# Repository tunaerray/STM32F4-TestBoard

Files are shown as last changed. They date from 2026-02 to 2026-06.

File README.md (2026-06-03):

# STM32F405RGT6 Test Board Hardware Design

A custom-designed embedded development and test board based on the **STM32F405RGT6** microcontroller.
This project focuses on creating a reliable, protected, and programmable STM32-based hardware platform with multiple communication interfaces and a robust power architecture.

## Overview

The board was designed as a programmable STM32F405RGT6-based embedded development platform. It includes common communication interfaces such as **UART**, **I2C**, and **USB**, along with power input protection and programming support.

The hardware design also includes protection mechanisms for safer operation, such as reverse polarity protection, overcurrent protection, and USB ESD protection.

## Features

* STM32F405RGT6 microcontroller
* UART communication interface
* I2C communication interface
* USB interface
* SWD programming support
* External 16 MHz clock circuit
* 12V external power input support
* USB 5V power input support
* Reverse polarity protection
* Overcurrent protection
* USB ESD protection
* Buck converter-based power stage
* 4-layer PCB design
* Signal integrity and power integrity considerations

## Hardware Design

The board includes two different power input paths:

* **12V external input**
* **USB 5V input**

Both input paths were designed with protection in mind. The external power input includes reverse polarity and overcurrent protection, while the USB line includes ESD protection to improve reliability during development and testing.

A buck converter-based power stage is used to generate a safe and stable voltage level for the STM32 microcontroller and peripheral circuits.

## PCB Design

The PCB was designed as a **4-layer board** to improve routing quality, power distribution, and signal integrity.
The layout was created by considering:

* Power integrity
* Signal integrity
* Proper decoupling
* Short and clean clock routing
* Stable MCU power delivery
* USB and communication line protection

## Images

### PCB Front

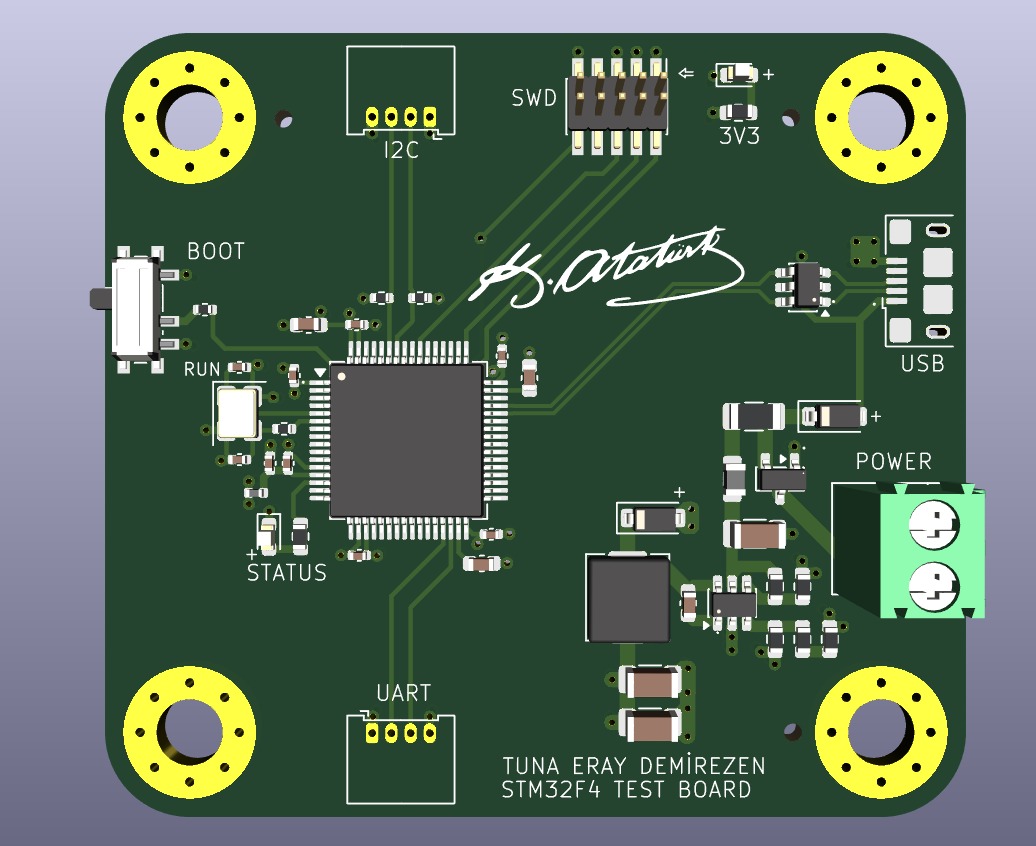
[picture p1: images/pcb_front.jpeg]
PCB Front


### PCB Back

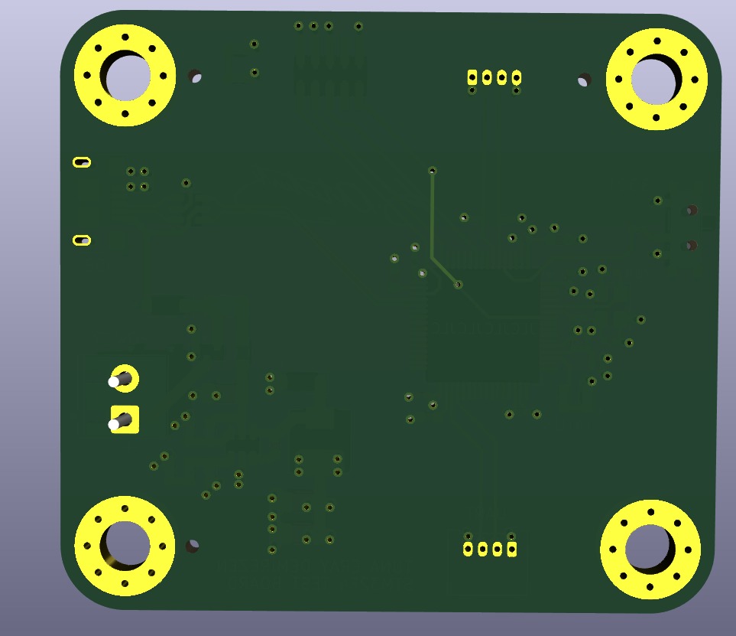
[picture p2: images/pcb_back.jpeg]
PCB Back


## Project Purpose

The main purpose of this project is to create a reliable STM32F405RGT6-based test and development board that can be used for embedded software development, peripheral testing, and hardware validation.

## Technologies Used

* STM32F405RGT6
* KiCad
* 4-layer PCB design
* Buck converter power stage
* UART
* I2C
* USB
* SWD programming interface

## Status

Hardware design completed and PCB files prepared for production.

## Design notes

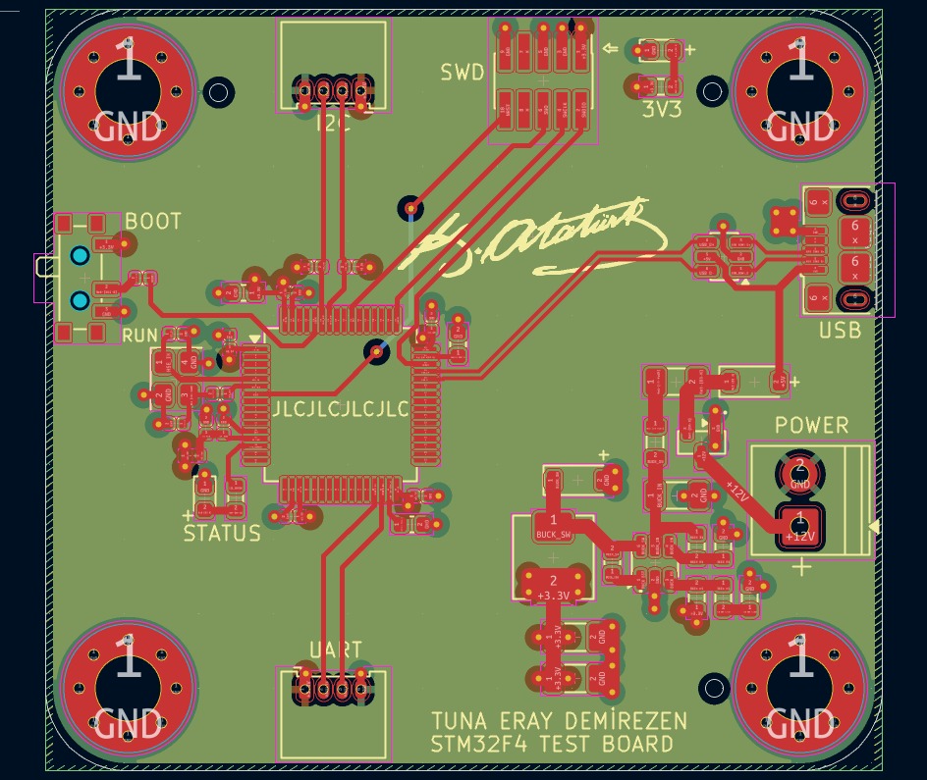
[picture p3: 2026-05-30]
images/pcb_layout.jpeg

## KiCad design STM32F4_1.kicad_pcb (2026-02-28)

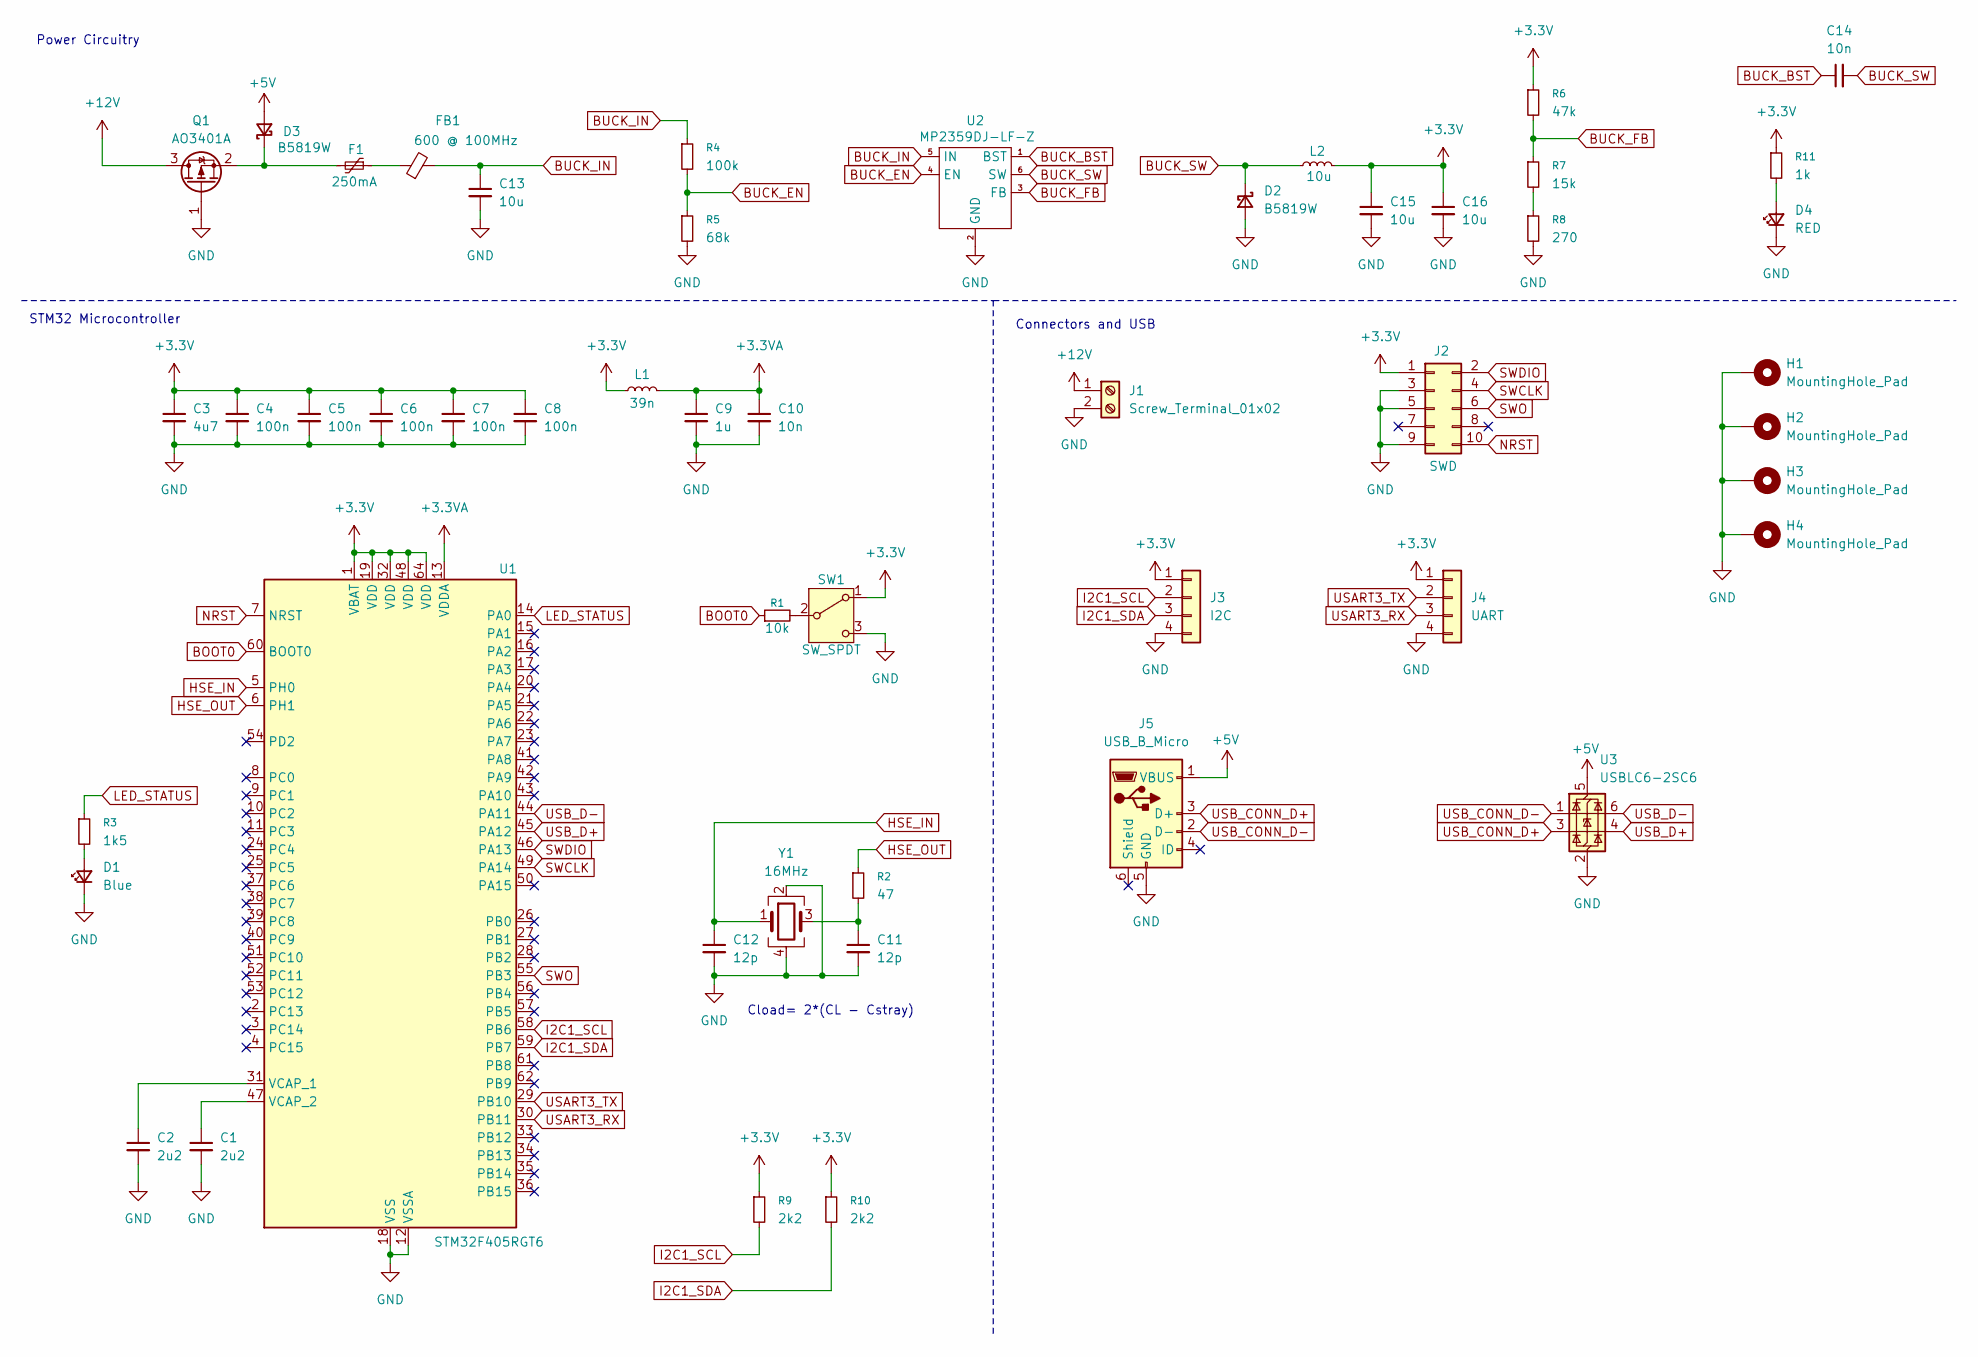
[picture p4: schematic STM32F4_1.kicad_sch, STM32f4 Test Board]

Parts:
C1, C2: 2u2; C_0603_1608Metric
C3: 4u7; C_0603_1608Metric
C4, C5, C6, C7, C8: 100n; C_0402_1005Metric
C9: 1u; C_0402_1005Metric
C10: 10n; C_0402_1005Metric
C11, C12: 12p; C_0402_1005Metric
C13, C15, C16: 10u; C_1206_3216Metric
C14: 10n; C_0603_1608Metric
D1: Blue; LED_0603_1608Metric
D2, D3: B5819W; D_SOD-123
D4: RED; LED_0603_1608Metric
F1: 250mA; Fuse_1206_3216Metric
FB1: 600 @ 100MHz; L_0805_2012Metric
H1, H2, H3, H4: MountingHole_Pad; MountingHole_4.3mm_M4_Pad_Via
J1: Screw_Terminal_01x02; TerminalBlock_Phoenix_PT-1,5-2-3.5-H_1x02_P3.50mm_Horizontal
J2: SWD; PinHeader_2x05_P1.27mm_Vertical_SMD
J3: I2C; Molex_PicoBlade_53048-0410_1x04_P1.25mm_Horizontal
J4: UART; Molex_PicoBlade_53048-0410_1x04_P1.25mm_Horizontal
J5: USB_B_Micro; USB_Micro-B_Amphenol_10118193-0002LF_Horizontal
L1: 39n; L_0402_1005Metric
L2: 10u; L_Sunlord_MWSA0518S
Q1: AO3401A; SOT-23
R1: 10k; R_0402_1005Metric
R2: 47; R_0402_1005Metric
R3: 1k5; R_0603_1608Metric
R4: 100k; R_0603_1608Metric
R5: 68k; R_0603_1608Metric
R6: 47k; R_0603_1608Metric
R7: 15k; R_0603_1608Metric
R8: 270; R_0603_1608Metric
R9, R10: 2k2; R_0402_1005Metric
R11: 1k; R_0603_1608Metric
SW1: SW_SPDT; SW_SPDT_PCM12
U1: STM32F405RGT6; LQFP-64_10x10mm_P0.5mm
U2: MP2359DJ-LF-Z; TSOT-23-6
U3: USBLC6-2SC6; SOT-23-6
Y1: 16MHz; Crystal_SMD_3225-4Pin_3.2x2.5mm

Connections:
+3.3V: C3.1, C4.1, C5.1, C6.1, C7.1, C8.1, C15.1, C16.1, J2.1, J3.1, J4.1, L1.1, L2.2, R6.1, R9.1, R10.1, R11.1, SW1.1 (A), U1.1 (VBAT), U1.19 (VDD), U1.32 (VDD), U1.48 (VDD), U1.64 (VDD)
+3.3VA: C9.1, C10.1, L1.2, U1.13 (VDDA)
+5V: D3.2 (A), J5.1 (VBUS), U3.5 (VBUS)
+12V: J1.1, Q1.3 (D)
BOOT0: R1.1, U1.60 (BOOT0)
BUCK_BST: C14.1, U2.1 (BST)
BUCK_EN: R4.2, R5.1, U2.4 (EN)
BUCK_FB: R6.2, R7.1, U2.3 (FB)
BUCK_IN: C13.1, FB1.2, R4.1, U2.5 (IN)
BUCK_SW: C14.2, D2.1 (K), L2.1, U2.6 (SW)
GND: C1.2, C2.2, C3.2, C4.2, C5.2, C6.2, C7.2, C8.2, C9.2, C10.2, C11.2, C12.2, C13.2, C15.2, C16.2, D1.1 (K), D2.2 (A), D4.1 (K), H1.1, H2.1, H3.1, H4.1, J1.2, J2.3, J2.5, J2.9, J3.4, J4.4, J5.5 (GND), Q1.1 (G), R5.2, R8.2, SW1.3 (C), U1.12 (VSSA), U1.18 (VSS), U1.63 (VSS), U2.2 (GND), U3.2 (GND), Y1.2, Y1.4
HSE_IN: C12.1, U1.5 (PH0), Y1.1
HSE_OUT: R2.1, U1.6 (PH1)
I2C1_SCL: J3.2, R9.2, U1.58 (PB6)
I2C1_SDA: J3.3, R10.2, U1.59 (PB7)
LED_STATUS: R3.1, U1.14 (PA0)
NRST: J2.10, U1.7 (NRST)
unnamed: C11.1, R2.2, Y1.3
unnamed: D1.2 (A), R3.2
unnamed: D3.1 (K), F1.2, Q1.2 (S)
unnamed: D4.2 (A), R11.2
unnamed: F1.1, FB1.1
unnamed: R7.2, R8.1
unnamed: R1.2, SW1.2 (B)
unnamed: C2.1, U1.31 (VCAP_1)
unnamed: C1.1, U1.47 (VCAP_2)
SWCLK: J2.4, U1.49 (PA14)
SWDIO: J2.2, U1.46 (PA13)
SWO: J2.6, U1.55 (PB3)
USART3_RX: J4.3, U1.30 (PB11)
USART3_TX: J4.2, U1.29 (PB10)
USB_CONN_D+: J5.3 (D+), U3.3 (I/O2)
USB_CONN_D-: J5.2 (D-), U3.1 (I/O1)
USB_D+: U1.45 (PA12), U3.4 (I/O2)
USB_D-: U1.44 (PA11), U3.6 (I/O1)

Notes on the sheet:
STM32 Microcontroller
Power Circuitry
Connectors and USB
Cload= 2*(CL - Cstray)

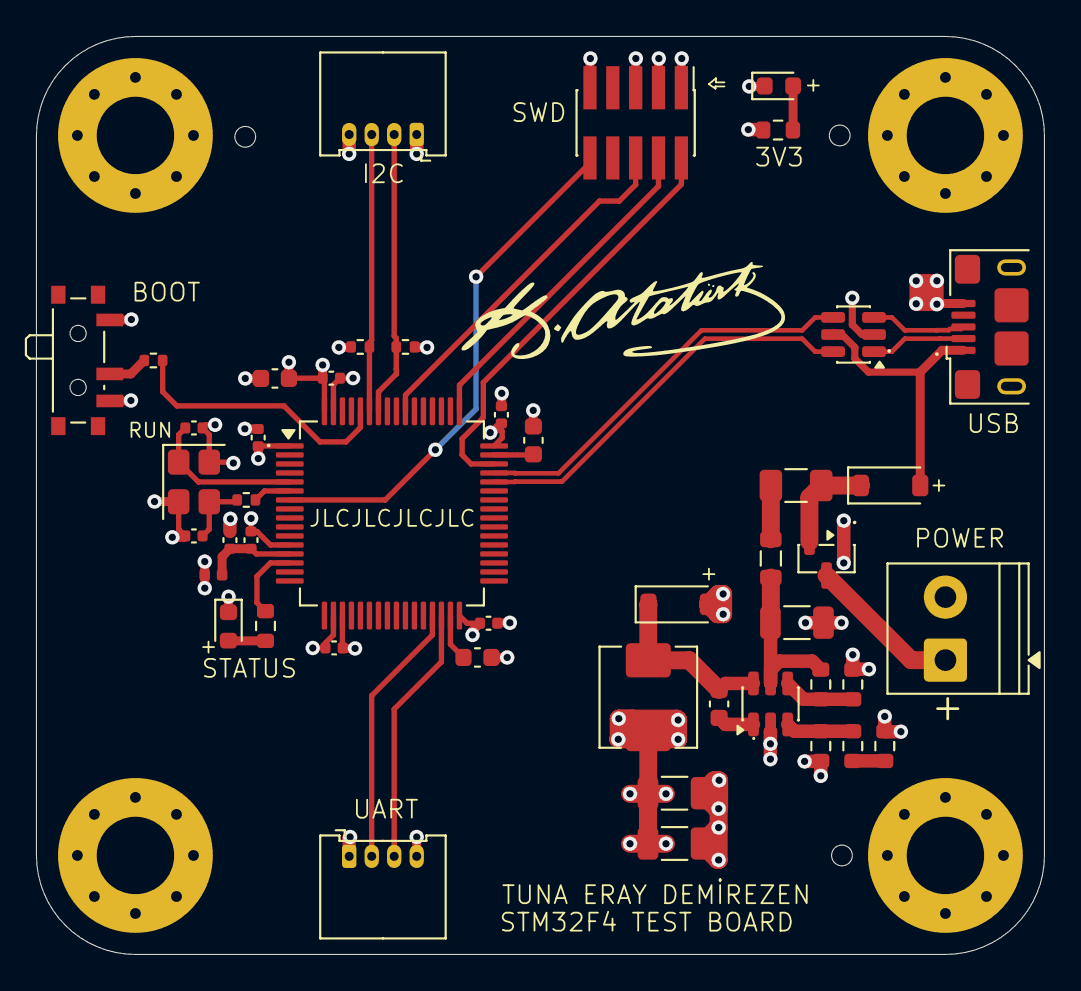
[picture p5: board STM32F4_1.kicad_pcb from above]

Board: 4 copper layers, 56.0 x 51.0 mm, 50 parts (0 on the bottom side), 35 nets.

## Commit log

2026-05-30 Add PCB images
2026-06-03 Add README for STM32F405RGT6 Test Board
    This README.md provides an overview of the STM32F405RGT6 test board hardware design, detailing features, hardware design considerations, PCB design, and project purpose.
